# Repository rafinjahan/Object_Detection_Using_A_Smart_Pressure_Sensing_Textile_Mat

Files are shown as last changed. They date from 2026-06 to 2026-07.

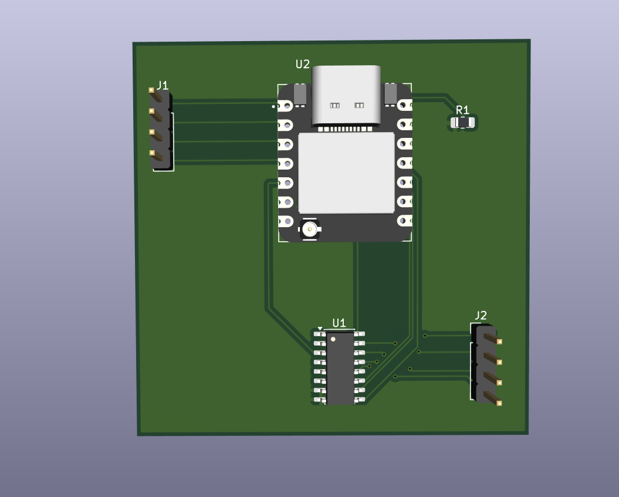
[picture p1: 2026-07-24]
hardware/pcb_object1.png

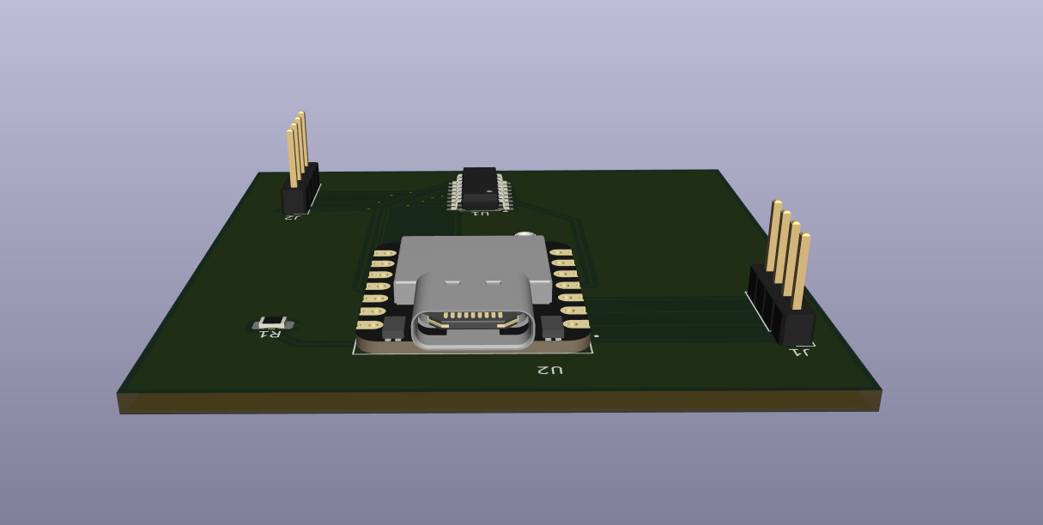
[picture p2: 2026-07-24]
hardware/pcb_object_top.png

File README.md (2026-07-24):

# Object Detection Using a Smart Pressure-Sensing Textile Mat

This repository contains the Python code and dataset for my bachelor thesis. The project uses a 4x4 woven piezoresistive pressure mat to classify everyday kitchen objects. It uses a Random Forest machine learning model to read the pressure footprint and total weight.
I designed a custom printed circuit board using KiCad to upgrade the original breadboard prototype. This custom PCB connects the textile mat directly to the microcontroller and multiplexer for a reliable system. You can see 3D screenshots of the finished board in the images folder.

## Hardware Setup
* 4x4 piezoresistive textile mat
* Seeed Studio XIAO ESP32S3 microcontroller
* CD74HC4051E analog multiplexer

## Software Dependencies
* Python 3
* pandas
* numpy
* scikit-learn
* matplotlib
* pyserial

## Project Structure
* `code/` contains all Python scripts.
* `data/` contains CSV datasets and measurement files.
* `hardware/` contains the KiCad PCB project and Gerber manufacturing files and the 3D model of the PCB.
* `images/` contains generated PNG plots and confusion matrices.
* `thesis/` contains thesis-related files.

## Project Files
* `data/tablecloth_dataset_flattened.csv` contains the recorded dataset of physical placements.
* `code/thesis_project.py` reads serial data and saves new placements to the dataset.
* `code/live_classifier.py` trains the model and shows real time predictions on a heatmap.
* `code/confusin_matrix_result.py` calculates grouped cross validation accuracy and generates the confusion matrix.

## How It Works
The microcontroller scans the 16 sensor nodes on the fabric. Custom data acquisition software stabilizes the analog signals and filters out background noise. The system sends the pressure data to a computer for real time visualization and recording. The Python script reads this data stream and updates a visual heatmap. The system includes a noise limit of 150 ADC units. When the pressure goes above this limit the Random Forest model predicts which object is on the mat.

## Tested Objects
The dataset includes eight different classes.
* Iittala plate empty and full
* Kotikulta Ulappa bowl empty and full
* Arabia Muumi cup empty and full
* 0.33 L Coca-Cola can full
* 1.5 L Sprite bottle full

## Future Work
Future improvements could include increasing the spatial resolution of the textile sensor. Another step is deploying the trained classifier directly on the microcontroller using a TinyML framework to improve user privacy.

## Instructions

The physical setup requires connecting the textile matrix to the microcontroller and multiplexer.

1. Connect the four row pins of the 4x4 piezoresistive textile mat to the digital output pins of the microcontroller.
2. Connect the four column pins of the mat to the analog multiplexer inputs.
3. Ensure the microcontroller and multiplexer share a common ground and a stable 3.3V power supply.
4. Connect the microcontroller to the data collection computer using a USB cable.

## Microcontroller Setup (Arduino IDE)

Before running the Python scripts, you must program the microcontroller and verify it is reading the sensors correctly.

1. Install the Arduino IDE and add support for the Seeed Studio XIAO ESP32S3 board.
2. Open the provided `.ino` file in the Arduino IDE and upload it to the microcontroller.
3. Open the Serial Monitor in the Arduino IDE (set the baud rate to 115200).
4. Apply pressure to different parts of the mat. You should see a stream of numbers appearing in the Serial Monitor. If the output changes when you press the mat, the hardware is working correctly.
5. **Important:** Close the Arduino Serial Monitor before running the Python scripts, otherwise Python will not be able to connect to the serial port.

## Software Installation (Python)

The software pipeline requires Python 3 and several scientific computing libraries.

1. Install Python 3 on the data collection computer.
2. Create a virtual environment to manage the project dependencies.
3. Install the required libraries using the pip package manager.

`pip install pandas numpy scikit-learn matplotlib pyserial`

## Data Collection and Heatmap Visualization

The data collection script reads raw analog values from the serial port and visualizes the spatial pressure distribution.

1. Place the smart textile mat on a flat and rigid surface to ensure consistent pressure readings.
2. Run the data collection script from your terminal using `python data_collection.py`.
3. Observe the real time heatmap interface to verify all 16 sensor nodes respond correctly to physical pressure.
4. Place a test object on the mat and allow the sensor values to stabilize for a few seconds.
5. Press the designated keyboard key to record the current matrix values and the object label into the dataset file named `tablecloth_dataset_flattened.csv`.

## Model Training and Evaluation

The machine learning model uses the collected CSV dataset to train the Random Forest classifier.

1. Verify the dataset file contains sufficient samples for all tested object categories.
2. Run the model evaluation script from the terminal using `python model_evaluation.py`.
3. The script will automatically load the CSV dataset and format the spatial arrays into one dimensional features.
4. The Random Forest algorithm will train on the data and output the grouped cross validation accuracy results.
5. Review the generated confusion matrix image to analyze the classification performance across different objects.

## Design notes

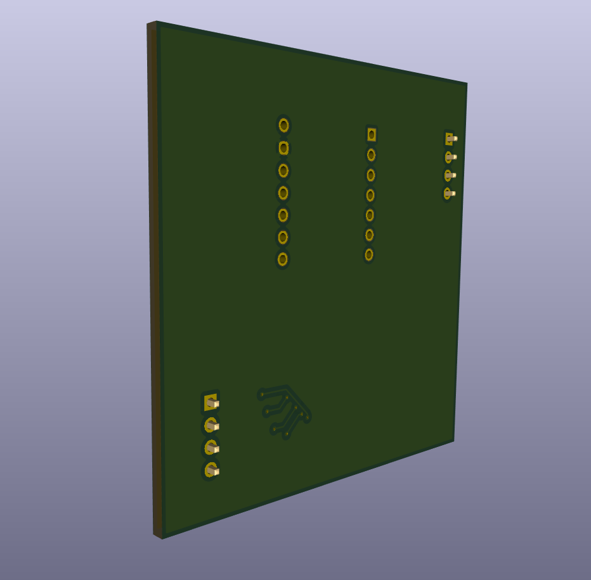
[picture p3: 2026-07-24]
hardware/pcb_object_back.png

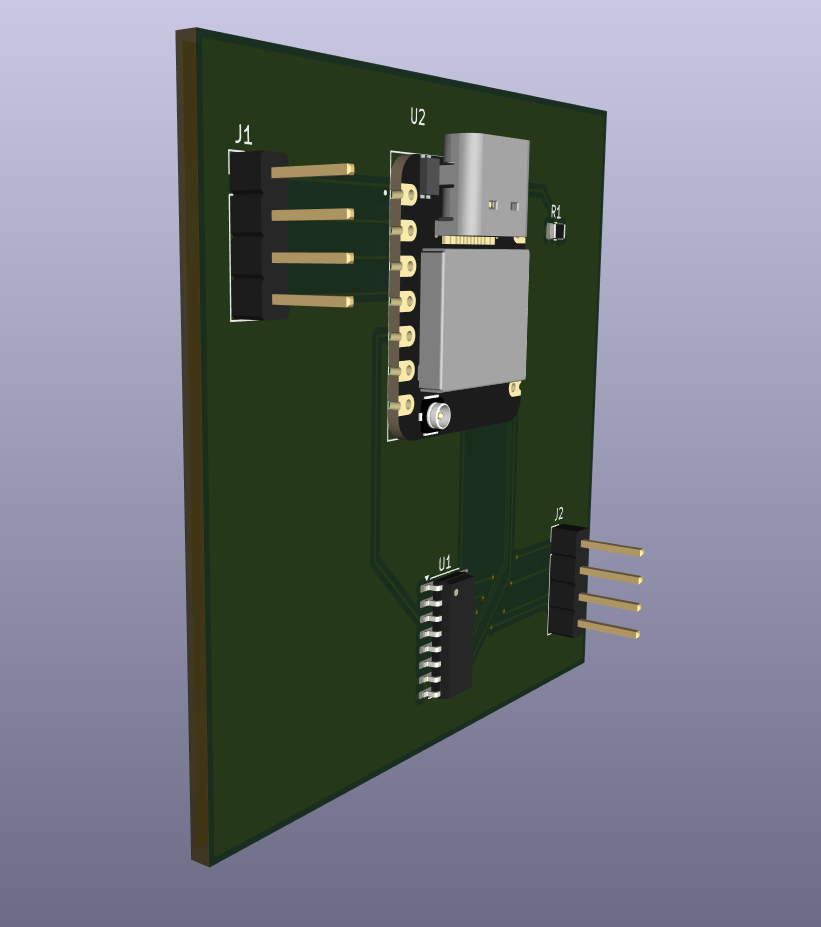
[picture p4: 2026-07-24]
hardware/pcb_object2.png

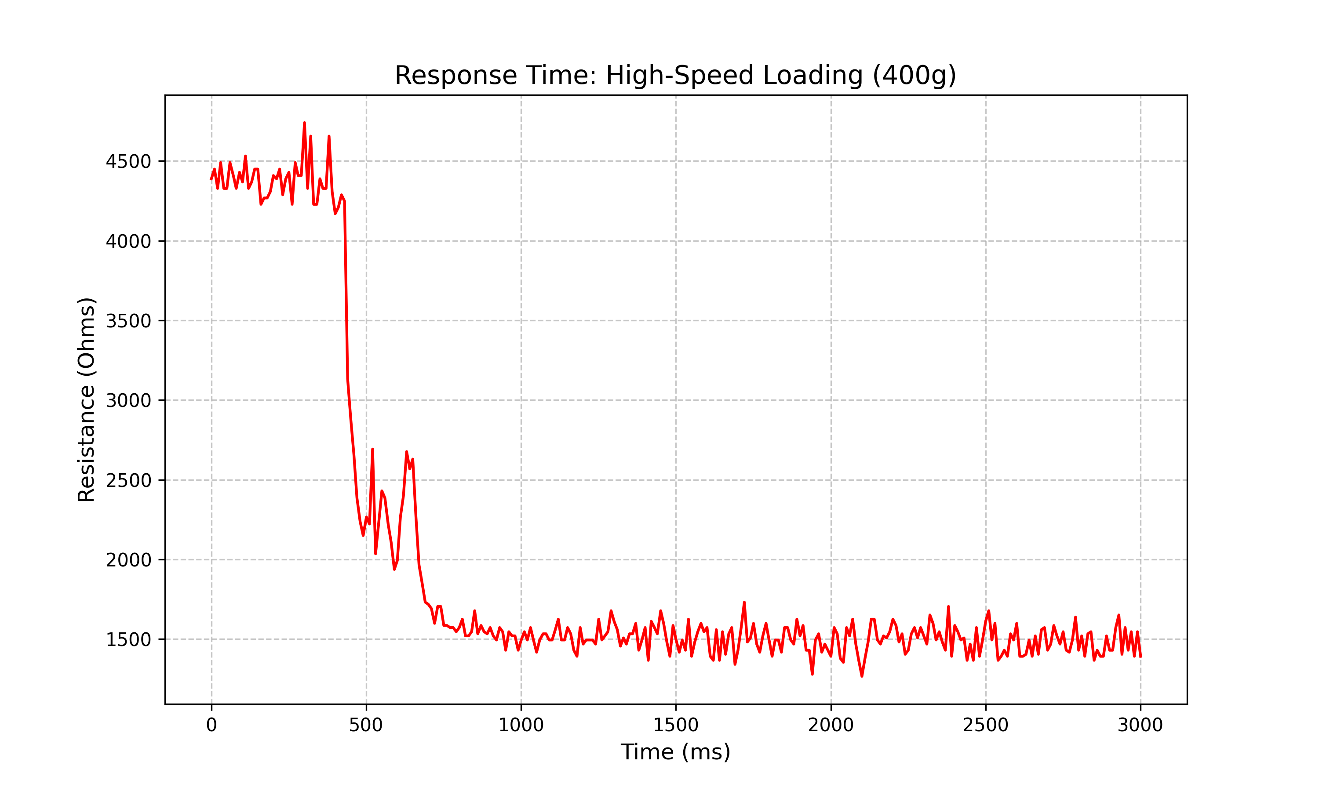
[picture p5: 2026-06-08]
images/response_plot.png

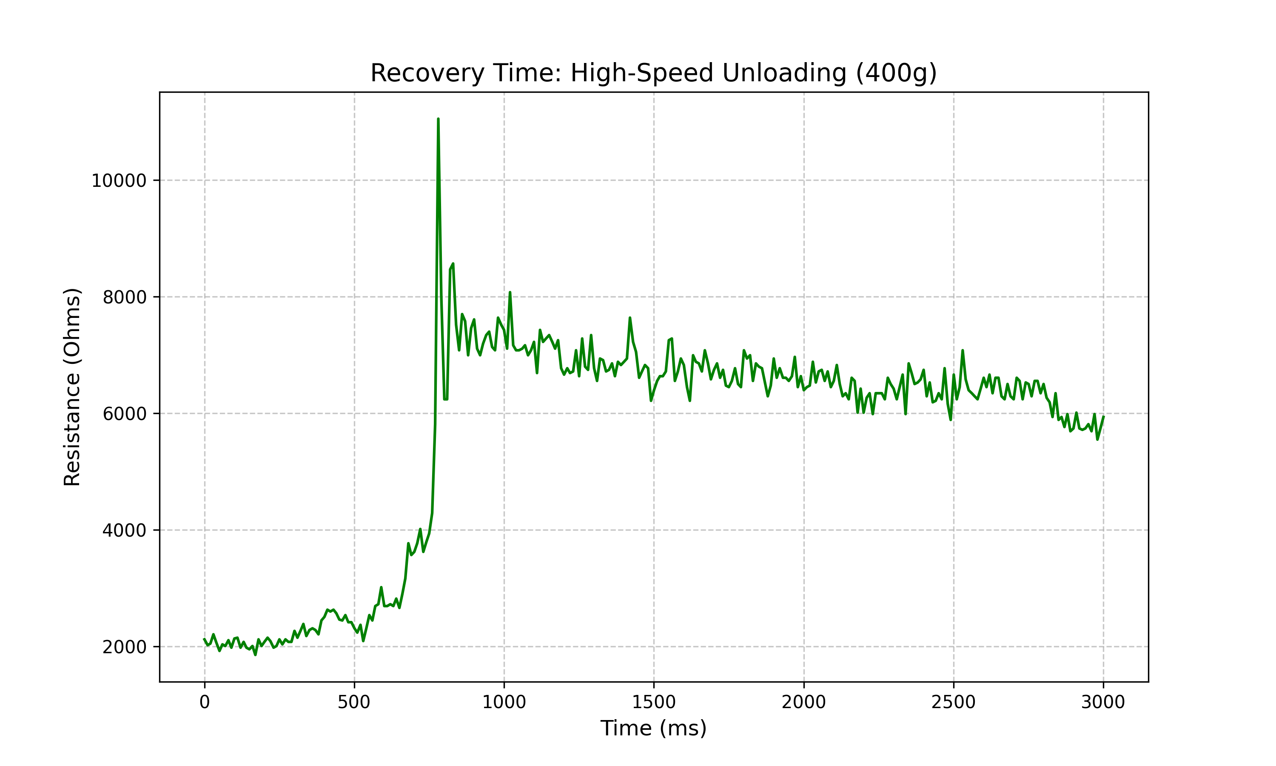
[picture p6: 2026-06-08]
images/recovery_plot.png

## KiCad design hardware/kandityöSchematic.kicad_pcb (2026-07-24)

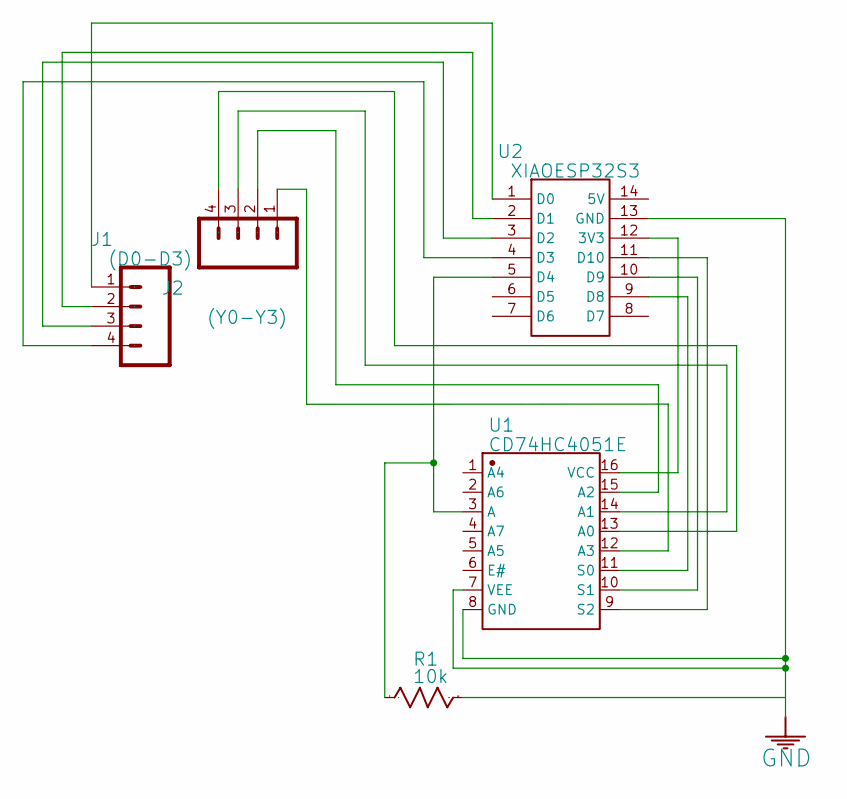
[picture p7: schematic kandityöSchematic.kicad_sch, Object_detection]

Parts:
J1: (D0-D3); PinHeader_1x04_P2.54mm_Vertical
J2: (Y0-Y3); PinHeader_1x04_P2.54mm_Vertical
R1: 10k; R_0805_2012Metric_Pad1.20x1.40mm_HandSolder
U1: CD74HC4051E; SOIC-16_3.9x9.9mm_P1.27mm; Manufacturer Part CD74HC4051E
U2: XIAOESP32S3; MODULE_XIAO_ESP32_S3

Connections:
GND: R1.1, U1.7 (VEE), U1.8 (GND), U2.13 (GND)
unnamed: J2.4, U1.13 (A0)
unnamed: J2.3, U1.14 (A1)
unnamed: J2.2, U1.15 (A2)
unnamed: J2.1, U1.12 (A3)
unnamed: R1.2, U1.3 (A), U2.5 (D4)
unnamed: U1.11 (S0), U2.9 (D8)
unnamed: U1.10 (S1), U2.10 (D9)
unnamed: U1.9 (S2), U2.11 (D10)
unnamed: U1.16 (VCC), U2.12 (3V3)
unnamed: J1.1, U2.1 (D0)
unnamed: J1.2, U2.2 (D1)
unnamed: J1.3, U2.3 (D2)
unnamed: J1.4, U2.4 (D3)

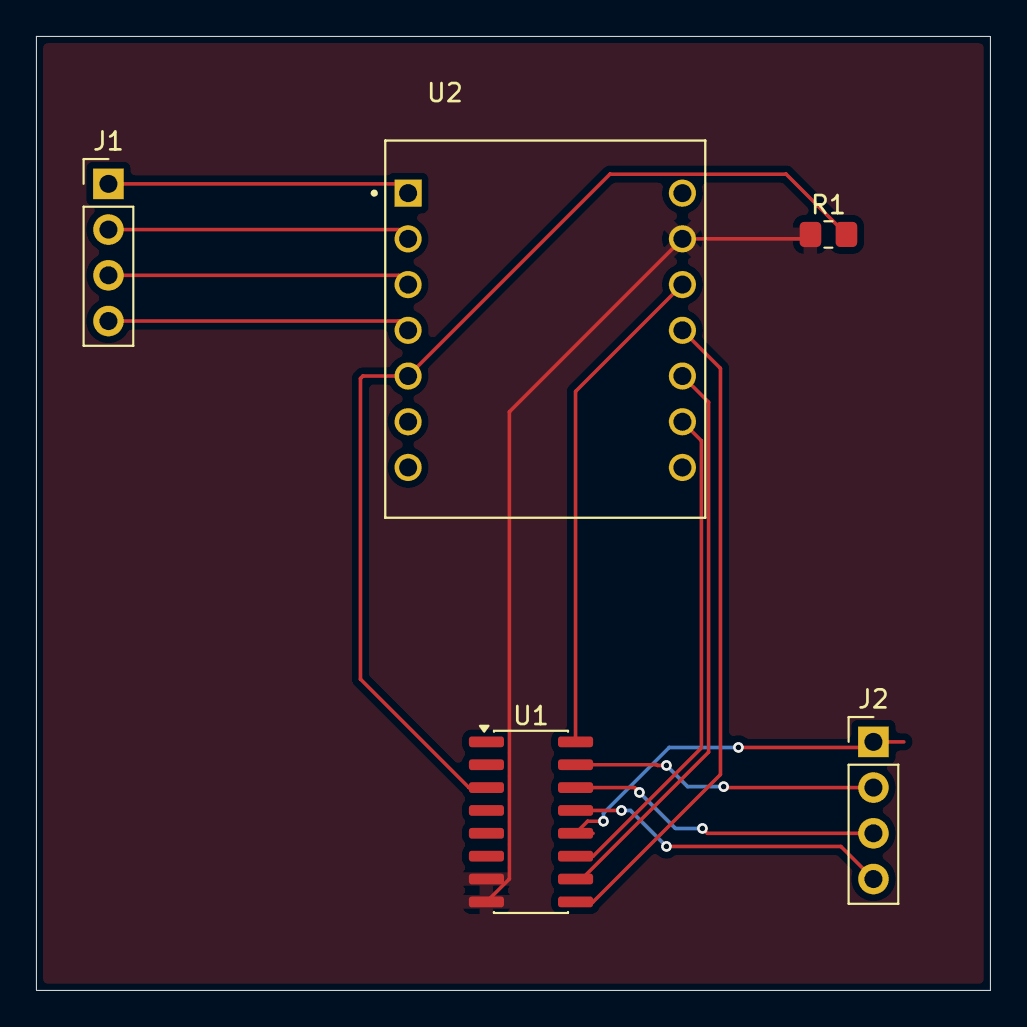
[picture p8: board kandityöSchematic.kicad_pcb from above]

Board: 2 copper layers, 53.0 x 53.0 mm, 5 parts (0 on the bottom side), 14 nets.

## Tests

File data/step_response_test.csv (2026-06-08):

timestamp | target_weight | resistance_ohms
1777470759.8496034 | 0 | 5044.12
1777470759.859519 | 0 | 5500.0
1777470759.8698845 | 0 | 5155.56
1777470759.8794942 | 0 | 5044.12
1777470759.889538 | 0 | 5314.37
1777470759.8995163 | 0 | 5291.48
1777470759.9094965 | 0 | 5268.66
1777470759.91977 | 0 | 5223.21
1777470759.9295206 | 0 | 5314.37
1777470759.93956 | 0 | 4934.31
1777470759.9494395 | 0 | 5110.78
1777470759.9593792 | 0 | 5044.12
1777470759.9694774 | 0 | 5044.12
1777470759.9803114 | 0 | 5000.0
1777470759.9895983 | 0 | 5245.9
1777470759.9996967 | 0 | 5268.66
1777470760.0093427 | 0 | 5245.9
1777470760.0196528 | 0 | 5133.14
1777470760.0294147 | 0 | 5268.66
1777470760.0394385 | 0 | 5268.66
1777470760.0494049 | 0 | 5000.0
1777470760.059371 | 0 | 5044.12
1777470760.0695248 | 0 | 4847.6
1777470760.079475 | 0 | 5245.9
1777470760.0894034 | 0 | 5223.21
1777470760.099414 | 0 | 4804.63
1777470760.1093338 | 0 | 5044.12
1777470760.119499 | 0 | 5133.14
1777470760.1293712 | 0 | 4783.24
1777470760.1393883 | 0 | 5110.78
1777470760.1493714 | 0 | 5088.5
1777470760.1595383 | 0 | 5088.5
1777470760.1695018 | 0 | 5223.21
1777470760.1793406 | 0 | 5268.66
1777470760.1894655 | 0 | 5110.78
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

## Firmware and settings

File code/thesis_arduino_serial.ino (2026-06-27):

const int muxS0 = D8;
const int muxS1 = D9;
const int muxS2 = D10; // Pinned to GND
const int muxSig = D4; 

// Rows for the pressure matrix
const int rows[] = {D0, D1, D2, D3}; 
const int rowCount = 4;
const int colCount = 4; // 4x4 matriisi

void setup() {
  Serial.begin(115200);

  pinMode(muxS0, OUTPUT);
  pinMode(muxS1, OUTPUT);
  pinMode(muxS2, OUTPUT);
  
  digitalWrite(muxS2, LOW); 

  for (int i = 0; i < rowCount; i++) {
    pinMode(rows[i], OUTPUT);
    digitalWrite(rows[i], LOW); 
  }
}

void loop() {
  for (int i = 0; i < rowCount; i++) {
    digitalWrite(rows[i], HIGH);

    for (int j = 0; j < colCount; j++) {
      setMuxChannel(j);
      
      // ADVISOR NOTE: Increased delay to let voltage stabilize
      delayMicroseconds(100); 

      analogRead(muxSig); 
      
      // Actual read
      int val = analogRead(muxSig); 

      Serial.print(val);
      Serial.print("\t");
    }
    
    digitalWrite(rows[i], LOW);
    
    // move to a new line after every row is finished
    Serial.println(); 
  }
  
  // draw a line between each full 4x4 scan
  Serial.println("----"); 
  delay(500);
}

void setMuxChannel(int channel) {
  digitalWrite(muxS0, bitRead(channel, 0));
  digitalWrite(muxS1, bitRead(channel, 1));
}

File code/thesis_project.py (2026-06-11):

import serial
import numpy as np
import matplotlib.pyplot as plt
import json
import csv
import time
import os

for key in plt.rcParams:
    if key.startswith('keymap.'):
        plt.rcParams[key] = []

script_folder = os.path.dirname(os.path.abspath(__file__))
project_root = os.path.dirname(script_folder)
filename = os.path.join(project_root, "data", "tablecloth_dataset_flattened.csv")

counts_file = os.path.join(project_root, "thesis", "record_counts.json")

try:
    with open(counts_file, 'r') as cf:
        record_counts = json.load(cf)
except Exception:
    record_counts = {}

if not os.path.exists(filename):
    with open(filename, 'w', newline='') as f:
        writer = csv.writer(f, delimiter=';')
        writer.writerow(["time", "item", "state", "p0", "p1", "p2", "p3", "p4", "p5", "p6", "p7", "p8", "p9", "p10", "p11", "p12", "p13", "p14", "p15"])

PORT = 'COM3' 
BAUD = 115200

try:
    ser = serial.Serial(PORT, BAUD, timeout=1)
except Exception:
    print(f"Could not connect to {PORT}. Check connection.")
    exit()

plt.ion()
fig, ax = plt.subplots()
matrix = np.zeros((4, 4))

im = ax.imshow(matrix, cmap='hot', vmin=0, vmax=4095) 
plt.colorbar(im)
plt.title("Textile Pressure Mat (4x4)")

is_recording = False
current_item = ""
current_state = ""
frames_recorded = 0
buffer_data = [] 

TARGET_FRAMES = 1 

def on_key(event):
    global is_recording, current_item, current_state, frames_recorded, buffer_data
    
    key_map = {
        'q': ['bowl', 'empty'],
        'a': ['bowl', 'full'],
        'w': ['plate', 'empty'],
        's': ['plate', 'full'],
        'e': ['muumi_cup_arabia', 'empty'],
        'd': ['muumi_cup_arabia', 'full'],
        'f': ['coke_0.33l', 'full'],
        'g': ['coke_1.5l', 'full']
    }
    
    if event.key in key_map:
        if is_recording:
            print("Already recording... wait a moment.")
            return
            
        current_item = key_map[event.key][0]
        current_state = key_map[event.key][1]
        is_recording = True
        frames_recorded = 0
        buffer_data = [] 
        print(f"\n>>> RECORDING PLACEMENT FOR: {current_state} {current_item}")

fig.canvas.mpl_connect('key_press_event', on_key)

print("Ready. Make sure the heatmap window is active.")
print("Place object, then press its key to record ONE flattened placement.")

grid_data = []

while True:
    try:
        while ser.in_waiting > 0:
            line = ser.readline().decode('utf-8').strip()
            
            if line == "----":
                if len(grid_data) == 4:
                    matrix = np.array(grid_data)
                    im.set_data(matrix) 
                    
                    if is_recording:
                        flat_matrix = matrix.flatten().tolist()
                        buffer_data.append(flat_matrix)
                        frames_recorded += 1
                        print(".", end="", flush=True)
                        
                    
                        if frames_recorded >= TARGET_FRAMES:
                            is_recording = False
                            
                        
                            flattened_frame = np.mean(buffer_data, axis=0)
                            flattened_frame = np.round(flattened_frame).astype(int)
                            
                            
                            with open(filename, 'a', newline='') as f:
                                writer = csv.writer(f, delimiter=';')
                                row = [time.time(), current_item, current_state] + flattened_frame.tolist()
                                writer.writerow(row)
                           
                            record_counts[current_item] = record_counts.get(current_item, 0) + 1
                            try:
                                with open(counts_file, 'w') as cf:
                                    json.dump(record_counts, cf)
                            except Exception:
                                pass

                            print(f"\n||| PLACEMENT SAVED. {current_item} recorded {record_counts[current_item]} times. Move object to a new spot and press key again.")
                            buffer_data = []
                        
                grid_data = []
                
            elif line != "":
                row = [int(x) for x in line.split('\t') if x != ""]
                if len(row) == 4:
                    grid_data.append(row)
        
        plt.pause(0.001)
                    
    except KeyboardInterrupt:
        print("\nstopped by terminal.")
        break
    except Exception as e:
        pass

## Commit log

2026-06-08 Thesis code added
    Added all of the code
    [recovery_time_400g.csv, response_time_400g.csv, sensitivity_range32.csv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]
2026-06-11 Reorganize repository into code data images thesis folders
    [recovery_time_400g.csv, response_time_400g.csv, sensitivity_range32.csv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]
2026-06-27 Add Arduino code for pressure matrix reading
    Initialize multiplexer and read pressure matrix values.
2026-07-24 added harware KiCad files
    [kandityöSchematic-B_Cu.gbr, kandityöSchematic-B_Mask.gbr, kandityöSchematic-B_Paste.gbr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]
2026-07-24 Added PCB 3d pics
2026-07-24 Enhance README with PCB design information
    Added details about the custom PCB design and its components.
